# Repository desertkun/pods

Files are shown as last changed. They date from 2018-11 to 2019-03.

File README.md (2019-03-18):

# pods



Compact game console on `STM32F103RC6` chip with network module `NRF24L01` and `SH1106` display designed to be made as a pair.

To compile this, you'll need to install the [System Workbench for STM32](http://www.openstm32.org/Downloading%2Bthe%2BSystem%2BWorkbench%2Bfor%2BSTM32%2Binstaller) (requires an account to download).

The `layout` folder contains KiCad project for [schematics](https://user-images.githubusercontent.com/1666014/50406018-09bfe200-07c6-11e9-8298-aad8884d8a90.png).

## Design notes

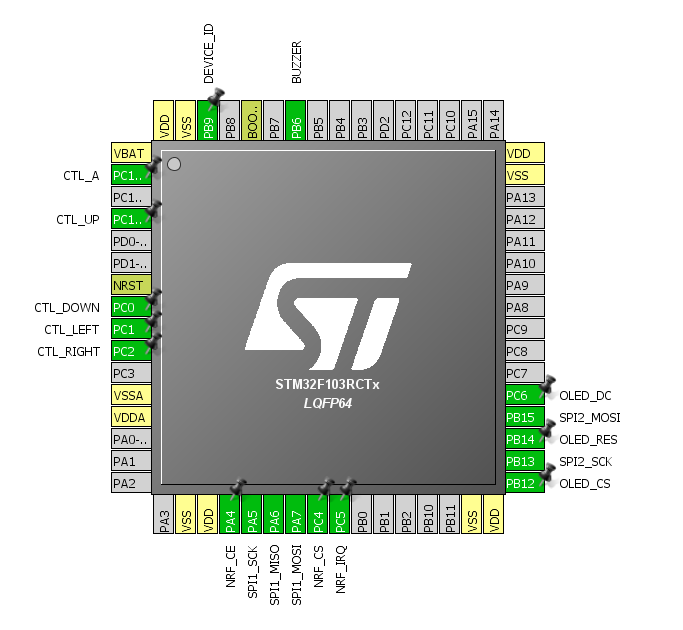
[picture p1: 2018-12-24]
datasheets/pinout.png

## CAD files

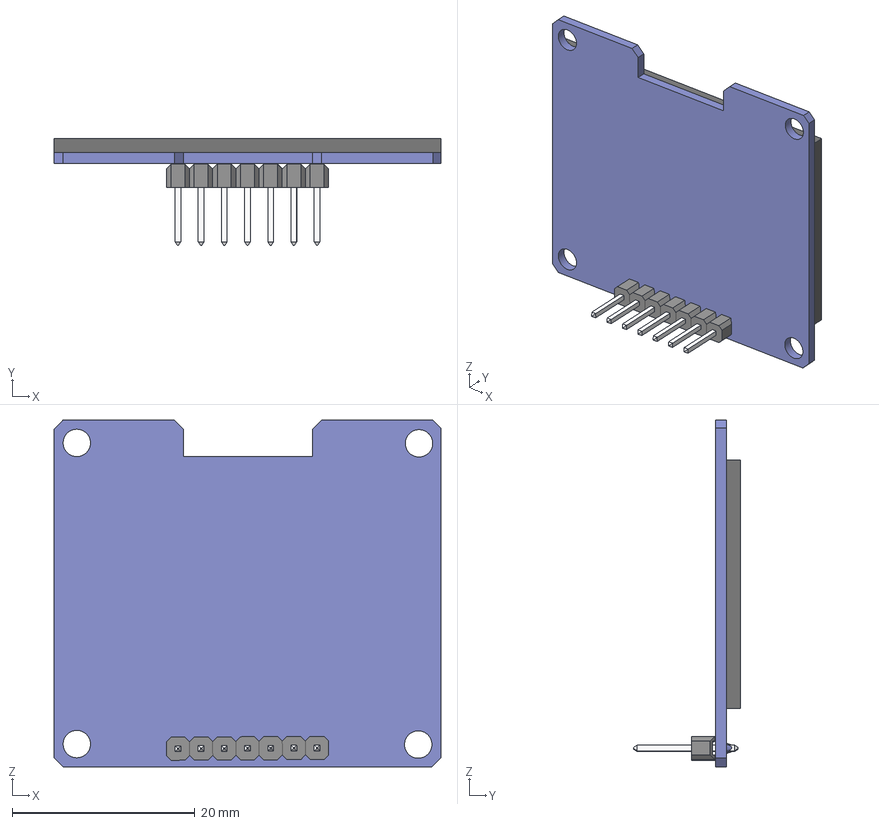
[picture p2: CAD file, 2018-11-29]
layout/3d/OLED Display 1.stp
42.4 x 11.7 x 38.0 mm

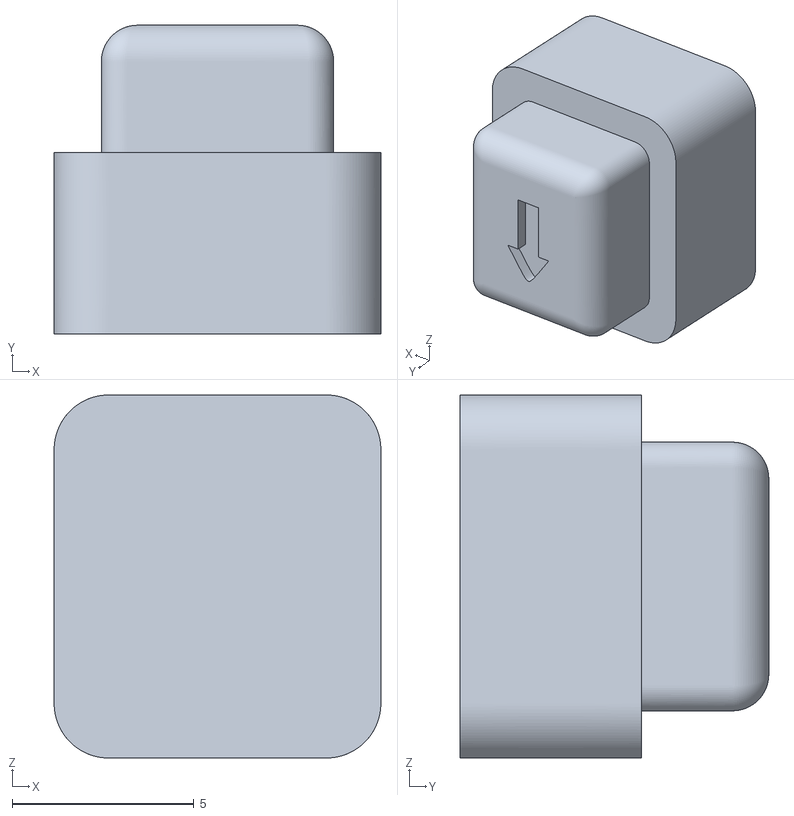
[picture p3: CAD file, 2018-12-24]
plot/3d/Arrow button.stl
9.00 x 8.50 x 10.0

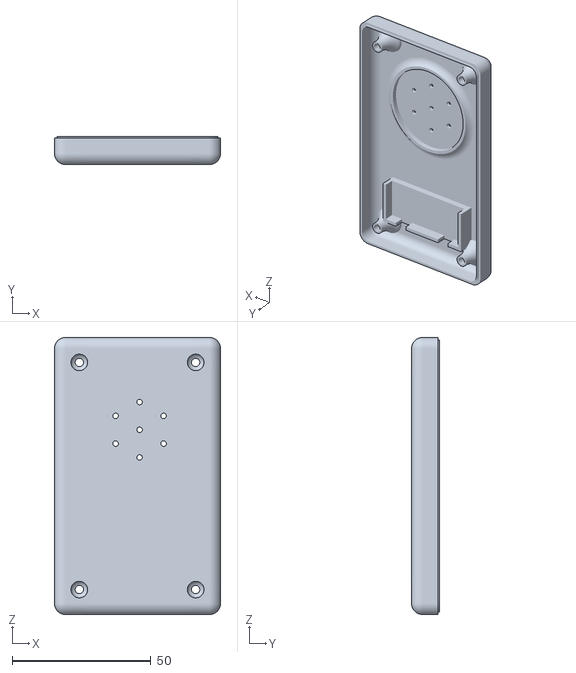
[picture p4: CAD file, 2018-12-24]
plot/3d/Bottom.stl
60.0 x 10.1 x 100.0

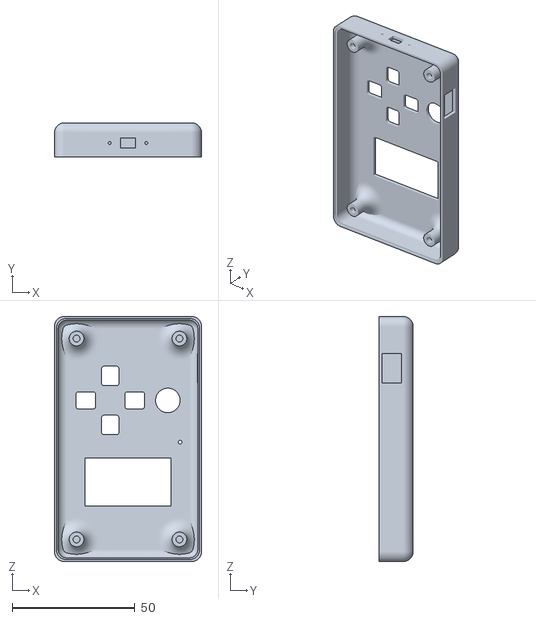
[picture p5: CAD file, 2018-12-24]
plot/3d/Top.stl
60.0 x 14.0 x 100.0

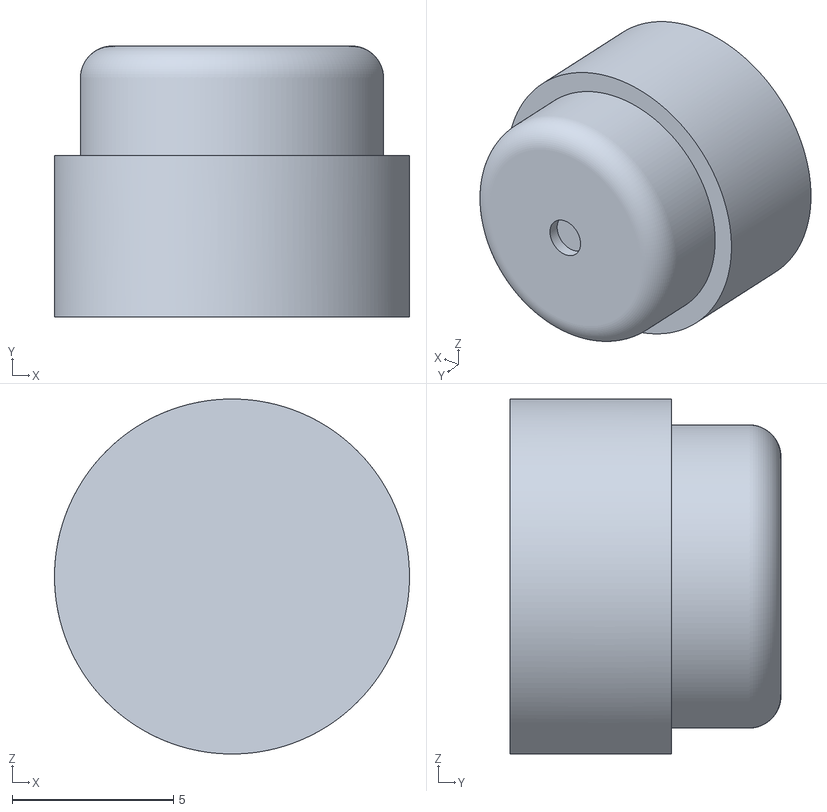
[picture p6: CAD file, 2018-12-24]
plot/3d/A button.stl
11.0 x 8.40 x 11.0

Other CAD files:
layout/3d/OLED Display 1.igs
layout/3d/OLED Display 1.stl

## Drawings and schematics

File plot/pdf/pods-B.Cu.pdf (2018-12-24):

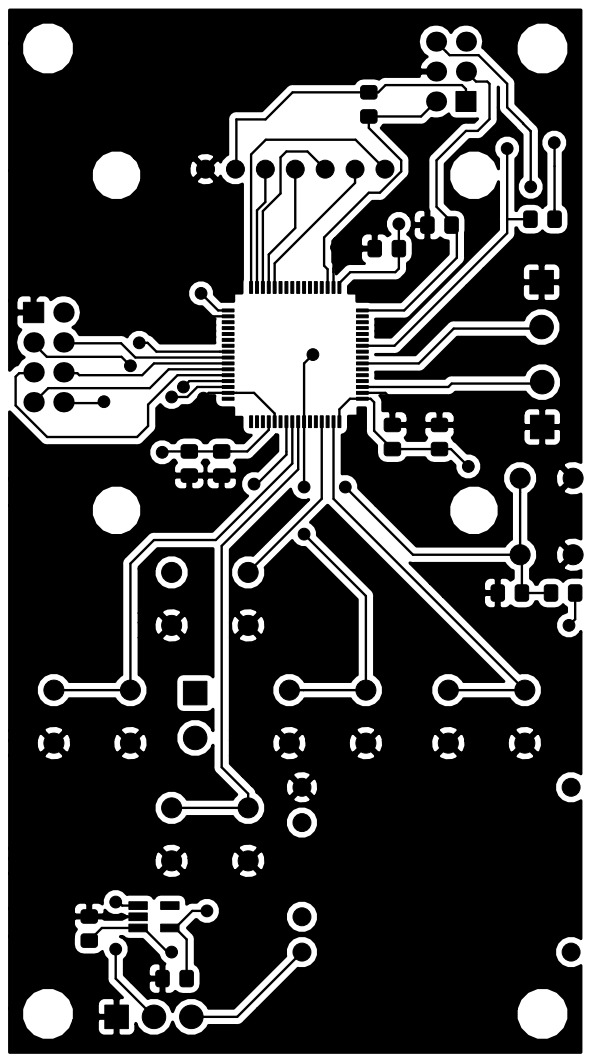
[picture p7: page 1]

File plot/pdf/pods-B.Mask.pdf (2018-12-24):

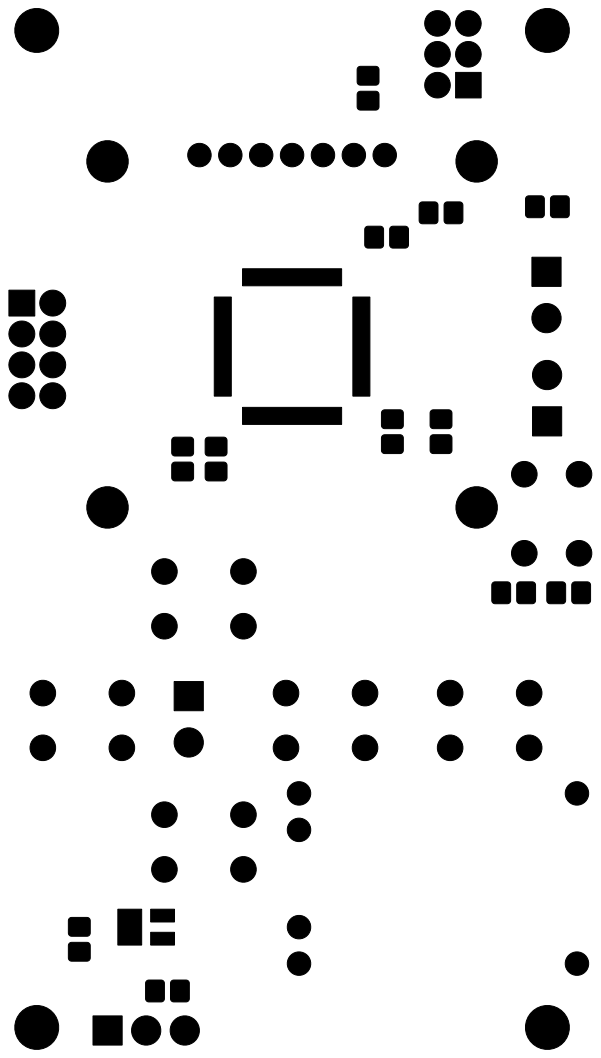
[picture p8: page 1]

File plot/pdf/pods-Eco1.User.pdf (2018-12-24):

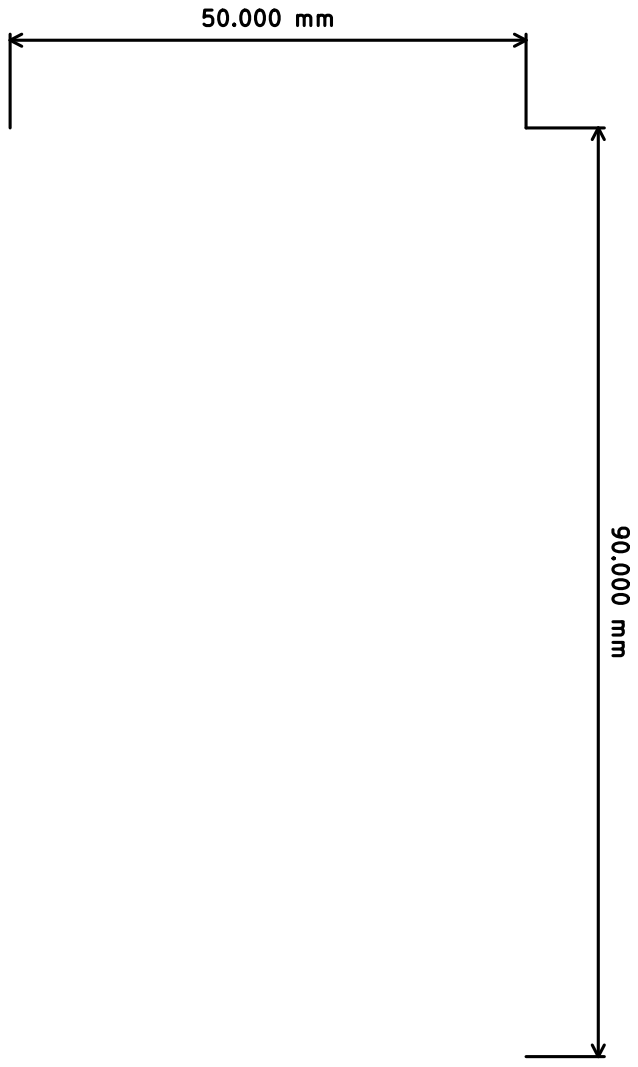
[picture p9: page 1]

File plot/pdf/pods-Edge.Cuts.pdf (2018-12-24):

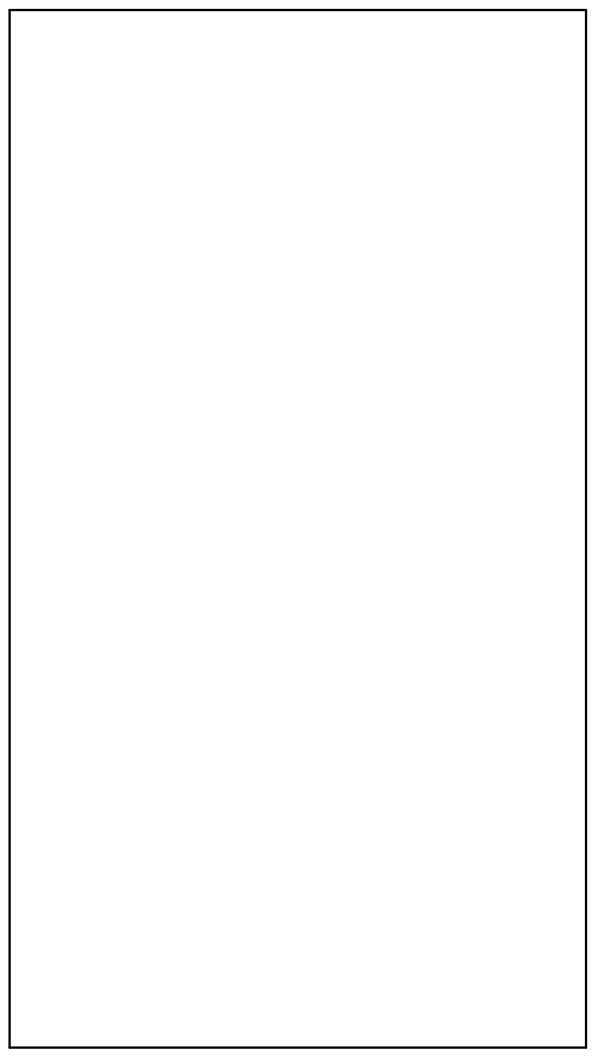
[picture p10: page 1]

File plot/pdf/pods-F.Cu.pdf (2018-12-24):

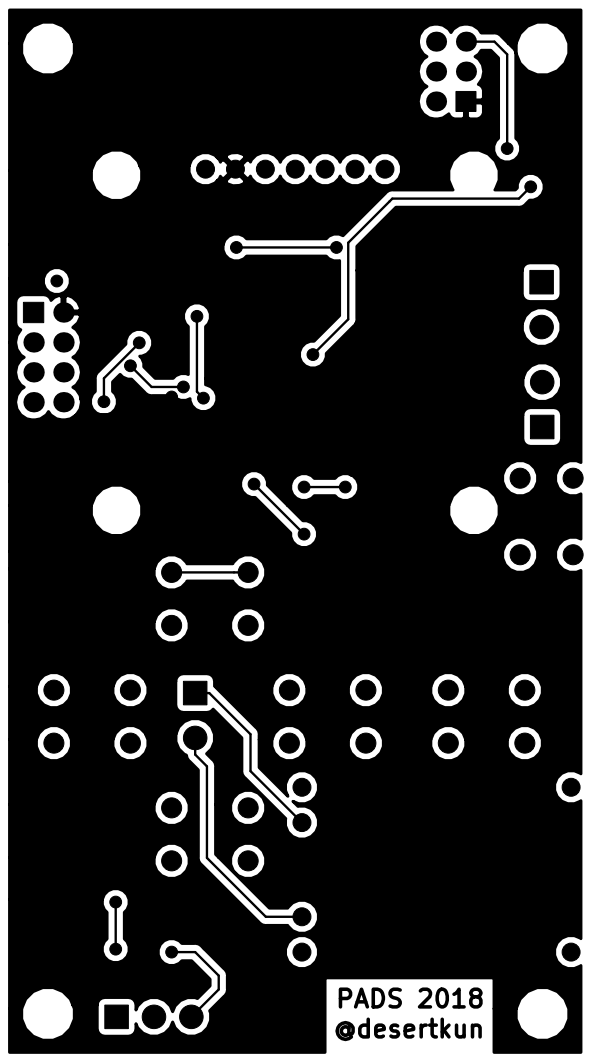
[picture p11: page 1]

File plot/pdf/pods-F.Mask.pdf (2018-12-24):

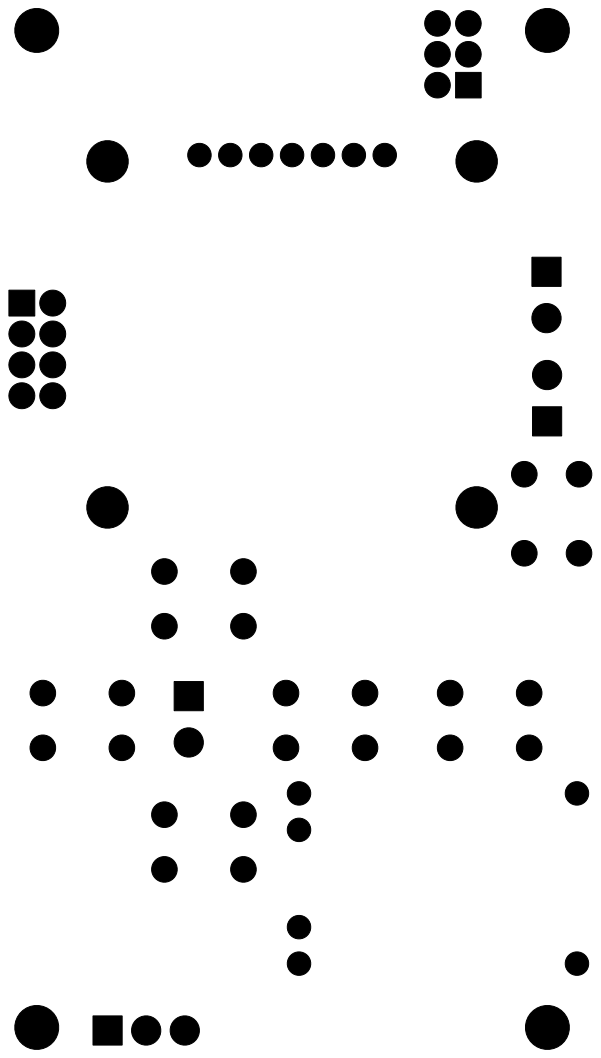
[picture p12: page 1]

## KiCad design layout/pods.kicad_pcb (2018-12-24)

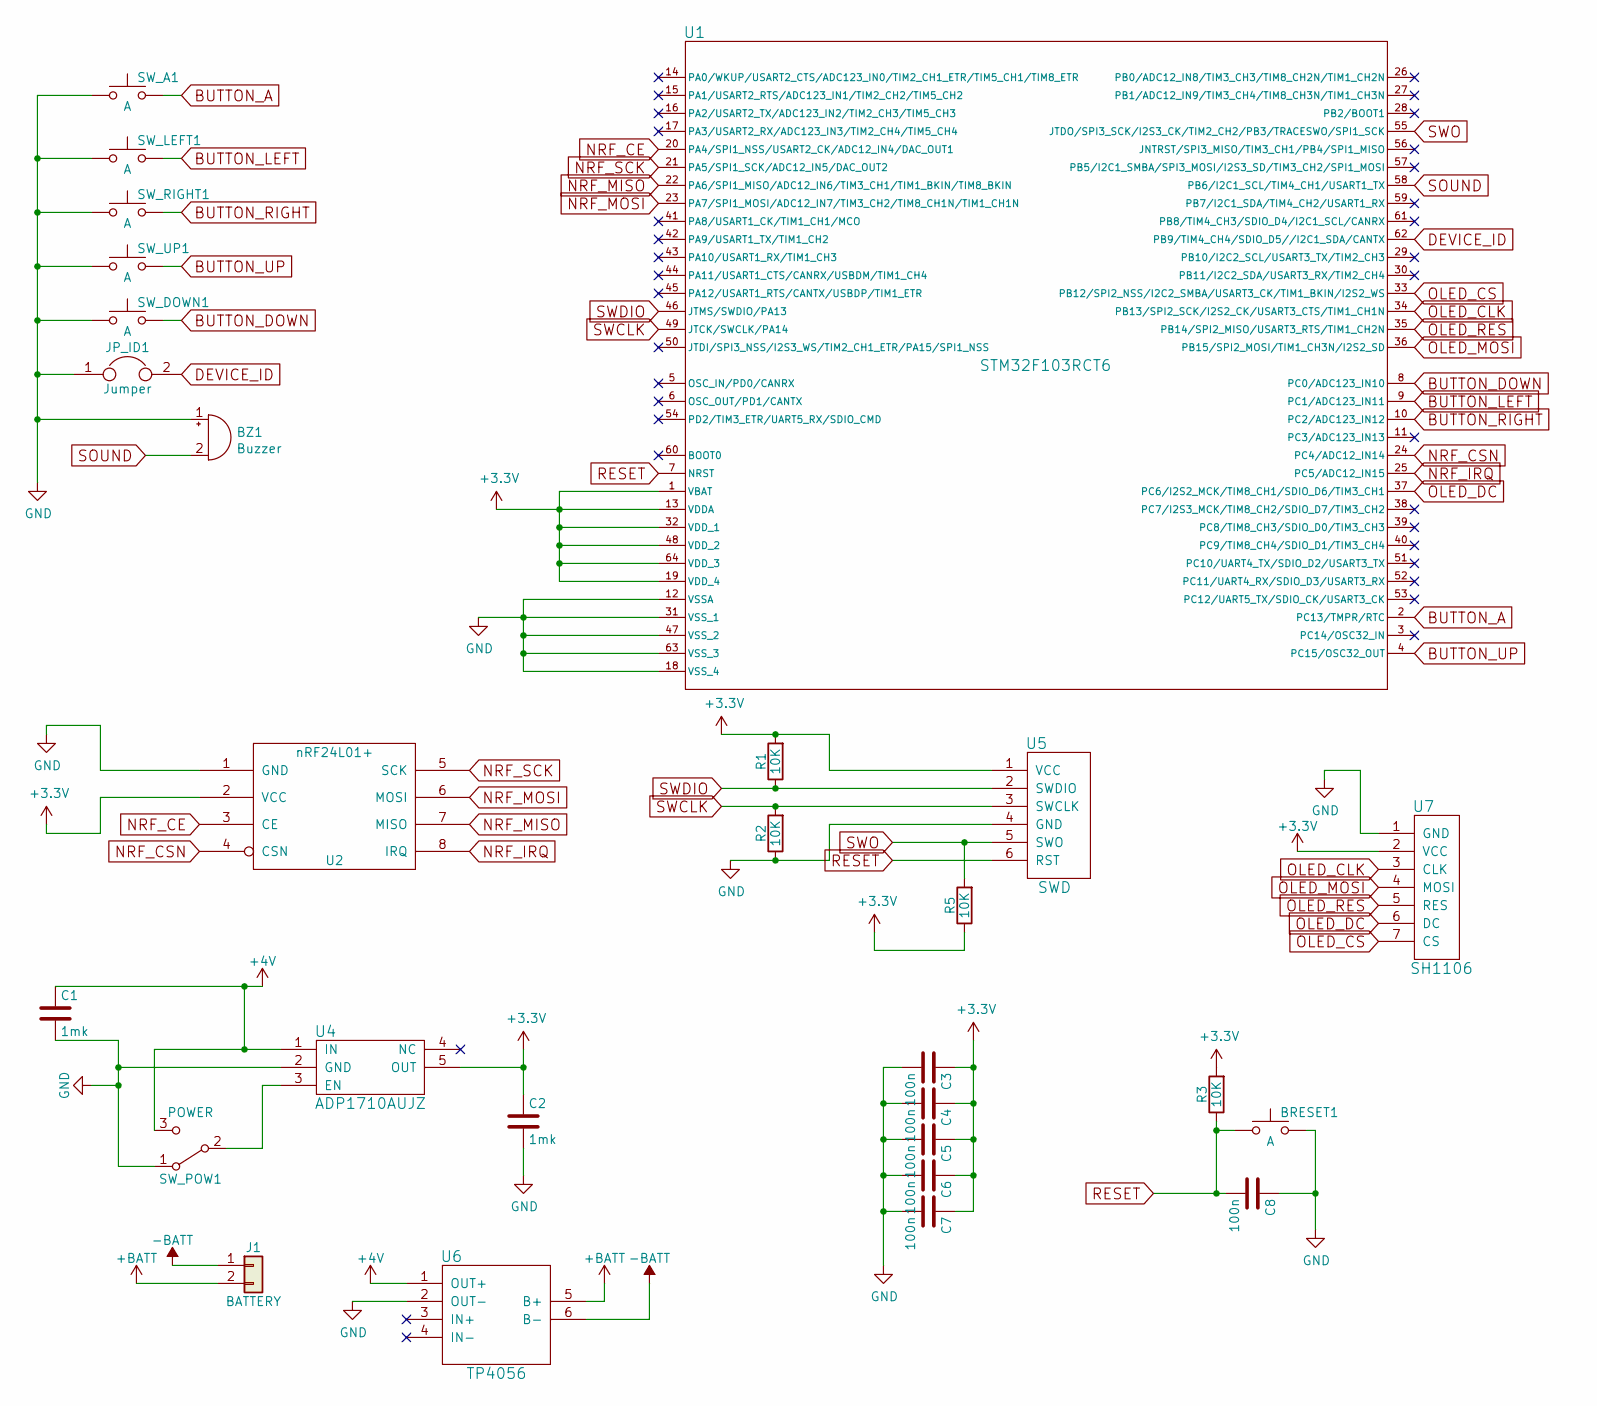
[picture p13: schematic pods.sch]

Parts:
BRESET1: A; SW_TH_Tactile_Omron_Fixed
BZ1: Buzzer; SolderWirePad_1x02_P3.81mm_Drill0.8mm
C1, C2: 1mk; C_0805_2012Metric_Pad1.15x1.40mm_HandSolder
C3, C4, C5, C6, C7, C8: 100n; C_0805_2012Metric_Pad1.15x1.40mm_HandSolder
J1: BATTERY; SolderWirePad_1x02_P3.81mm_Drill0.8mm
JP_ID1: Jumper; SolderWirePad_1x02_P3.81mm_Drill0.8mm
R1, R2, R3, R5: 10K; R_0805_2012Metric_Pad1.15x1.40mm_HandSolder
SW_A1: A; SW_TH_Tactile_Omron_Fixed
SW_DOWN1: A; SW_TH_Tactile_Omron_Fixed
SW_LEFT1: A; SW_TH_Tactile_Omron_Fixed
SW_POW1: POWER; SolderWirePad_1x03_P3.175mm_Drill0.8mm
SW_RIGHT1: A; SW_TH_Tactile_Omron_Fixed
SW_UP1: A; SW_TH_Tactile_Omron_Fixed
U1: STM32F103RCT6; LQFP-64_10x10mm_Pitch0.5mm
U2: nRF24L01+; NRF24L01
U4: ADP1710AUJZ; SOT-23-5_HandSoldering
U5: SWD; PinHeader_2x03_P2.54mm_Horizontal
U6: TP4056; tp4056
U7: SH1106; sh1106

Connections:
+3V3: C2.1, C3.1, C4.1, C5.1, C6.1, C7.1, R1.2, R3.2, R5.1, U1.1 (VBAT), U1.13 (VDDA), U1.19 (VDD_4), U1.32 (VDD_1), U1.48 (VDD_2), U1.64 (VDD_3), U2.2 (VCC), U4.5 (OUT), U5.1 (VCC), U7.2 (VCC)
+4V: C1.1, SW_POW1.3 (C), U4.1 (IN), U6.1 (OUT+)
+BATT: J1.2, U6.5 (B+)
-BATT: J1.1, U6.6 (B-)
BUTTON_A: SW_A1.2, U1.2 (PC13/TMPR/RTC)
BUTTON_DOWN: SW_DOWN1.2, U1.8 (PC0/ADC123_IN10)
BUTTON_LEFT: SW_LEFT1.2, U1.9 (PC1/ADC123_IN11)
BUTTON_RIGHT: SW_RIGHT1.2, U1.10 (PC2/ADC123_IN12)
BUTTON_UP: SW_UP1.2, U1.4 (PC15/OSC32_OUT)
DEVICE_ID: JP_ID1.2, U1.62 (PB9/TIM4_CH4/SDIO_D5//I2C1_SDA/CANTX)
GND: BRESET1.2, BZ1.1 (-), C1.2, C2.2, C3.2, C4.2, C5.2, C6.2, C7.2, C8.1, JP_ID1.1, R2.1, SW_A1.1, SW_DOWN1.1, SW_LEFT1.1, SW_POW1.1 (A), SW_RIGHT1.1, SW_UP1.1, U1.12 (VSSA), U1.18 (VSS_4), U1.31 (VSS_1), U1.47 (VSS_2), U1.63 (VSS_3), U2.1 (GND), U4.2 (GND), U5.4 (GND), U6.2 (OUT-), U7.1 (GND)
NRF_CE: U1.20 (PA4/SPI1_NSS/USART2_CK/ADC12_IN4/DAC_OU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), U2.3 (CE)
NRF_CSN: U1.24 (PC4/ADC12_IN14), U2.4 (CSN)
NRF_IRQ: U1.25 (PC5/ADC12_IN15), U2.8 (IRQ)
NRF_MISO: U1.22 (PA6/SPI1_MISO/ADC12_IN6/TIM3_CH1/TIM1_B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), U2.7 (MISO)
NRF_MOSI: U1.23 (PA7/SPI1_MOSI/ADC12_IN7/TIM3_CH2/TIM8_C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), U2.6 (MOSI)
NRF_SCK: U1.21 (PA5/SPI1_SCK/ADC12_IN5/DAC_OUT2), U2.5 (SCK)
unnamed: SW_POW1.2 (B), U4.3 (EN)
OLED_CLK: U1.34 (PB13/SPI2_SCK/I2S2_CK/USART3_CTS/TIM1_C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), U7.3 (CLK)
OLED_CS: U1.33 (PB12/SPI2_NSS/I2C2_SMBA/USART3_CK/TIM1_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), U7.7 (CS)
OLED_DC: U1.37 (PC6/I2S2_MCK/TIM8_CH1/SDIO_D6/TIM3_CH1), U7.6 (DC)
OLED_MOSI: U1.36 (PB15/SPI2_MOSI/TIM1_CH3N/I2S2_SD), U7.4 (MOSI)
OLED_RES: U1.35 (PB14/SPI2_MISO/USART3_RTS/TIM1_CH2N), U7.5 (RES)
RESET: BRESET1.1, C8.2, R3.1, U1.7 (NRST), U5.6 (RST)
SOUND: BZ1.2 (+), U1.58 (PB6/I2C1_SCL/TIM4_CH1/USART1_TX)
SWCLK: R2.2, U1.49 (JTCK/SWCLK/PA14), U5.3 (SWCLK)
SWDIO: R1.1, U1.46 (JTMS/SWDIO/PA13), U5.2 (SWDIO)
SWO: R5.2, U1.55 (JTDO/SPI3_SCK/I2S3_CK/TIM2_CH2/PB3/TRAC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), U5.5 (SWO)

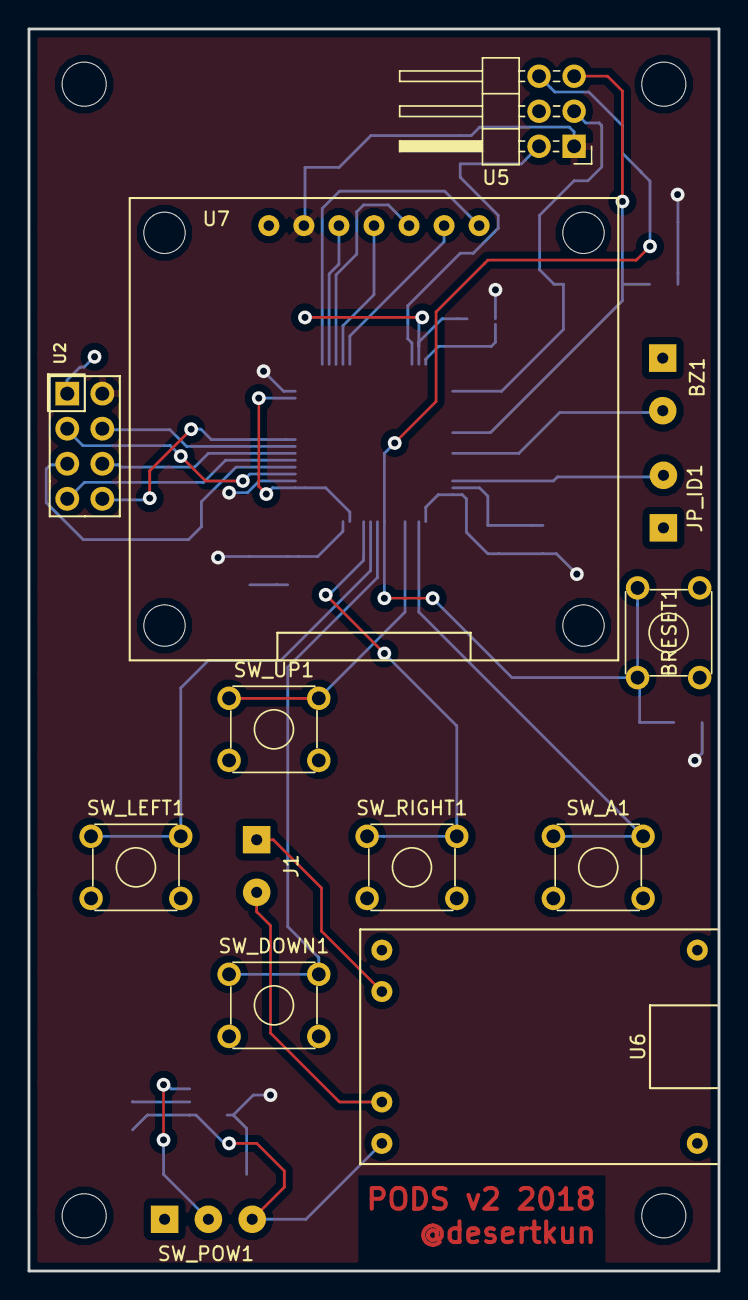
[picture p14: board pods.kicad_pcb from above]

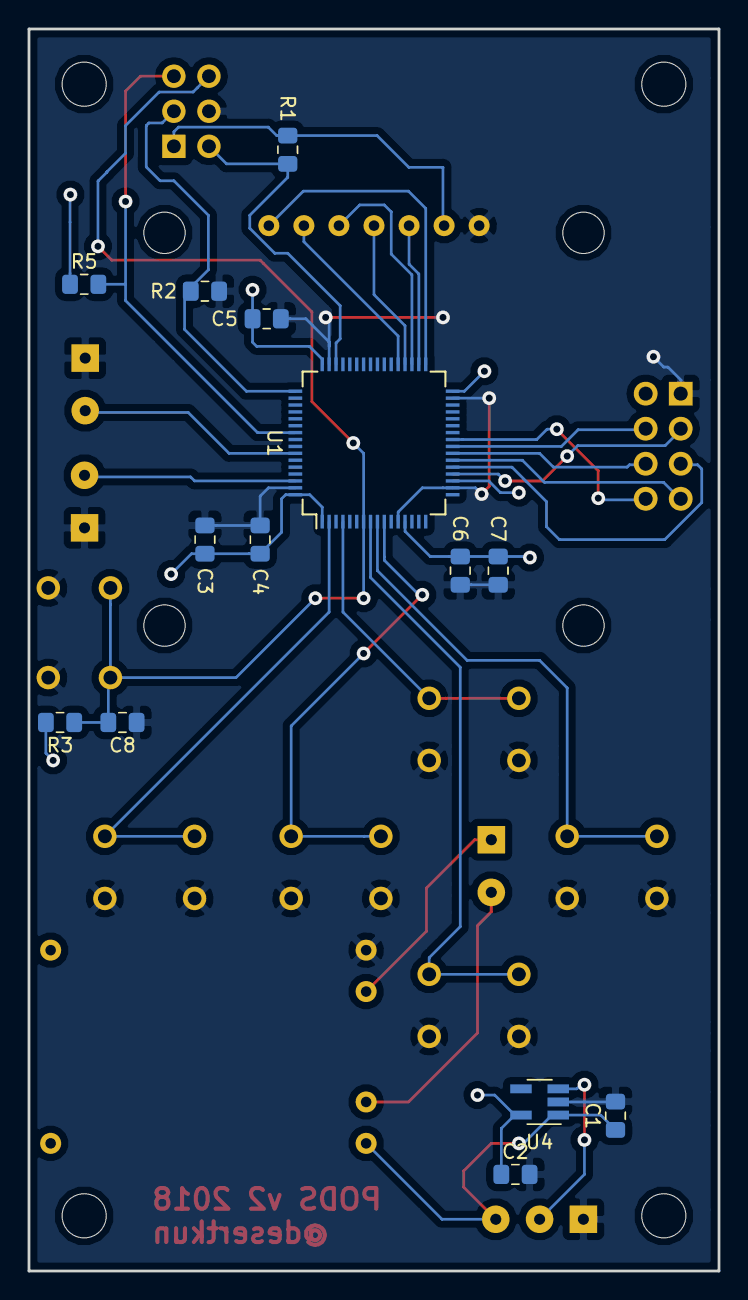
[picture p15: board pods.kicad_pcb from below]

Board: 2 copper layers, 50.0 x 90.0 mm, 28 parts (14 on the bottom side), 28 nets.

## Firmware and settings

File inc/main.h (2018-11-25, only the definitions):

#define CTL_A_Pin GPIO_PIN_13
#define CTL_A_GPIO_Port GPIOC
#define CTL_UP_Pin GPIO_PIN_15
#define CTL_UP_GPIO_Port GPIOC
#define CTL_DOWN_Pin GPIO_PIN_0
#define CTL_DOWN_GPIO_Port GPIOC
#define CTL_LEFT_Pin GPIO_PIN_1
#define CTL_LEFT_GPIO_Port GPIOC
#define CTL_RIGHT_Pin GPIO_PIN_2
#define CTL_RIGHT_GPIO_Port GPIOC
#define NRF_CE_Pin GPIO_PIN_4
#define NRF_CE_GPIO_Port GPIOA
#define NRF_CS_Pin GPIO_PIN_4
#define NRF_CS_GPIO_Port GPIOC
#define NRF_IRQ_Pin GPIO_PIN_5
#define NRF_IRQ_GPIO_Port GPIOC
#define NRF_IRQ_EXTI_IRQn EXTI9_5_IRQn
#define OLED_CS_Pin GPIO_PIN_12
#define OLED_CS_GPIO_Port GPIOB
#define OLED_RES_Pin GPIO_PIN_14
#define OLED_RES_GPIO_Port GPIOB
#define OLED_DC_Pin GPIO_PIN_6
#define OLED_DC_GPIO_Port GPIOC
#define BUZZER_Pin GPIO_PIN_6
#define BUZZER_GPIO_Port GPIOB
#define DEVICE_ID_Pin GPIO_PIN_9
#define DEVICE_ID_GPIO_Port GPIOB

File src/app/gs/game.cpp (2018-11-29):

/*
 * game.cpp
 *
 *  Created on: Mar 11, 2018
 *      Author: desertkun
 */


#include "app/gs/game.h"
#include "app/gs/mainmenu.h"
#include "app/gs/result.h"
#include "app/application.h"
#include "device/display.h"
#include "device/network.h"
#include "device/system.h"
#include "device/sound.h"
#include "app/melodies.h"
#include "app/messages.h"

#include <cstring>
#include <stdlib.h>

extern const unsigned char tile_wall_bmp [];
extern const unsigned char tile_block_bmp [];
extern const unsigned char tile_bomb_1_bmp [];
extern const unsigned char tile_bomb_2_bmp [];
extern const unsigned char tile_bomb_3_bmp [];
extern const unsigned char tile_bomb_4_bmp [];
extern const unsigned char tile_character_a_bmp [];
extern const unsigned char tile_character_b_bmp [];
extern const unsigned char tile_explosion_1_bmp [];
extern const unsigned char tile_explosion_2_bmp [];
extern const unsigned char tile_star_1_bmp [];
extern const unsigned char tile_star_2_bmp [];
extern const unsigned char tile_empty_bmp [];
extern const unsigned char tile_bomb_bonus_1_bmp [];
extern const unsigned char tile_bomb_bonus_2_bmp [];


namespace gs
{

Game Game::s_instance = Game();

int8_t sgn(int8_t val) {
    return (int8_t(0) < val) - (val < int8_t(0));
}

const uint32_t Bomb::TIME = 4000;
const uint32_t Bomb::EXPLOSION_TIME = 600;


void Bomb::place(uint8_t x, uint8_t y, uint8_t power)
{
	this->x = x;
	this->y = y;
	this->power = power;

	timer = 0;
	state = BombState::active;
	_render = true;

	device::Sound::playMelody(&Melodies::PlaceBomb[0]);

	Game::SetDirty();
}

void Bomb::removeExplosions()
{
	state = BombState::normal;
	timer = 0;

	Game& game = Game::s_instance;
	game.removeShake();

	game.setTile(x, y, Tile::empty);

	// left
	for (uint8_t _x = x - 1, p = power; _x >= 0 && p > 0; _x--, p--)
	{
		if (game.getTile(_x, y) != Tile::explosion)
			break;

		game.setTile(_x, y, Tile::empty);
	}

	// right
	for (uint8_t _x = x + 1, p = power; _x <= MAP_WIDTH - 1 && p > 0; _x++, p--)
	{
		if (game.getTile(_x, y) != Tile::explosion)
			break;

		game.setTile(_x, y, Tile::empty);
	}

	// up
	for (uint8_t _y = y - 1, p = power; _y >= 0 && p > 0; _y--, p--)
	{
		if (game.getTile(x, _y) != Tile::explosion)
			break;

		game.setTile(x, _y, Tile::empty);
	}

	// down
	for (uint8_t _y = y + 1, p = power; _y <= MAP_HEIGHT - 1 && p > 0; _y++, p--)
	{
		if (game.getTile(x, _y) != Tile::explosion)
			break;

		game.setTile(x, _y, Tile::empty);
	}

	Game::SetDirty();
}

void Bomb::explode()
{
	Game& game = Game::s_instance;

	device::Sound::playMelody(&Melodies::Bomb[0]);

	game.addShake();
	game.setTile(x, y, Tile::explosion);

	// left
	for (uint8_t _x = x - 1, p = power; _x >= 0 && p > 0; _x--, p--)
	{
		if (game.checkTile(_x, y))
			break;

		game.setTile(_x, y, Tile::explosion);
	}

	// right
	for (uint8_t _x = x + 1, p = power; _x <= MAP_WIDTH - 1 && p > 0; _x++, p--)
	{
		if (game.checkTile(_x, y))
			break;

		game.setTile(_x, y, Tile::explosion);
	}

	// up
	for (uint8_t _y = y - 1, p = power; _y >= 0 && p > 0; _y--, p--)
	{
		if (game.checkTile(x, _y))
			break;

		game.setTile(x, _y, Tile::explosion);
	}

	// down
	for (uint8_t _y = y + 1, p = power; _y <= MAP_HEIGHT - 1 && p > 0; _y++, p--)
	{
		if (game.checkTile(x, _y))
			break;

		game.setTile(x, _y, Tile::explosion);
	}

	state = BombState::explosion;
	timer = 0;

	Game::SetDirty();
}

void Bomb::update(uint32_t dt)
{
	switch (state)
	{
		case BombState::active:
		{
			timer += dt;

			bool now = timer % 500 > 250;

			if (now != _render)
			{
				_render = now;
				Game::SetDirty();
			}

			if (timer > Bomb::TIME)
			{
				explode();
			}

			break;
		}
		case BombState::explosion:
		{
			timer += dt;

			if (timer > Bomb::EXPLOSION_TIME)
			{
				removeExplosions();
			}

			Game::SetDirty();

			break;
		}
		default:
		{
			break;
		}
	}

}

void Bomb::render()
{
	if (state != BombState::active)
		return;

	const uint8_t* sprite;

	if (timer < 1000)
	{
		sprite = tile_bomb_1_bmp;
	}
	else if (timer < 2000)
	{
		sprite = tile_bomb_2_bmp;
	}
	else if (timer < 3000)
	{
		sprite = tile_bomb_3_bmp;
	}
	else
	{
		sprite = tile_bomb_4_bmp;
	}

	if (!_render)
		return;

	device::Display::drawImage(
		MAP_OFFSET_X + x * 8,
		MAP_OFFSET_Y + y * 8,
		8, 8, sprite);
}

///////////

void Player::moved()
{
	Game& game = Game::s_instance;

	Tile at = game.getTile(x, y);

	if (at == Tile::powerup)
	{
		device::Sound::playMelody(&Melodies::Pickup[0]);

		device::Display::invertDisplay(true);
		HAL_Delay(50);
		device::Display::invertDisplay(false);

		game.removePowerUp();
		game.setTile(x, y, Tile::empty);

		if (bombPower < 5)
			bombPower++;
	}

	if (at == Tile::extraBomb)
	{
		device::Sound::playMelody(&Melodies::Pickup[0]);

		device::Display::invertDisplay(true);
		HAL_Delay(50);
		device::Display::invertDisplay(false);

		game.removePowerUp();
		game.setTile(x, y, Tile::empty);

		if (bombCount < MAX_BOMBS)
			bombCount++;
	}
}

void Player::update(uint32_t dt)
{
	for (uint8_t i = 0; i < MAX_BOMBS; i++)
	{
		bombs[i].update(dt);
	}

	switch (state)
	{
		case PlayerState::moving:
		{
			movingTimer += dt;

			if (movingTimer >= 16)
			{
				movingTimer = 0;

				int8_t signX = sgn((int8_t)targetX - (int8_t)x),
					   signY = sgn((int8_t)targetY - (int8_t)y);

				offsetX += signX;
				offsetY += signY;
				movedBy += 1;

				Game::SetDirty();

				if (movedBy >= 8)
				{
					x = targetX;
					y = targetY;
					offsetX = 0;
					offsetY = 0;
					movedBy = 0;
					movingTimer = 0;
					state = PlayerState::normal;

					moved();
				}
			}


			break;
		}
		default:
		{
			break;
		}
	}
}

void Player::moveTo(uint8_t x, uint8_t y)
{
	targetX = x;
	targetY = y;
	offsetX = 0;
	offsetY = 0;
	movedBy = 0;
	movingTimer = 0;

	state = PlayerState::moving;
}

void Player::init(uint8_t x, uint8_t y, const unsigned char* sprite)
{
	this->x = x;
	this->y = y;
	this->sprite = sprite;

	for (uint8_t i = 0; i < MAX_BOMBS; i++)
	{
		Bomb& bomb = bombs[i];
		bomb.state = BombState::normal;
		bomb.timer = 0;
		bomb._render = false;
		bomb.power = 1;
	}

	bombPower = 1;
	bombCount = 1;
	offsetX = 0;
	offsetY = 0;
	movingTimer = 0;
	state = PlayerState::normal;
}

void Player::render()
{
	device::Display::drawImage(
		MAP_OFFSET_X + x * 8 + offsetX,
		MAP_OFFSET_Y + y * 8 + offsetY,
		8, 8, sprite);


	for (uint8_t i = 0; i < MAX_BOMBS; i++)
	{
		bombs[i].render();
	}
}

/////////
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

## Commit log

2018-03-10 Network working prototype
    [layout.fzz, stm_link_1.cfg, stm_link_2.cfg]
2018-11-21 Some progress
    [layout.fzz, pods-2018-11-21-16-58-43.sch, pods.kicad_pcb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]
2018-11-24 Working prototype
    Fixed network
    Full-blown music
    Moving characters
    [application.cpp, game.cpp, game.h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]
2018-11-29 New PCB design
    [OLED Display 1.igs, OLED Display 1.stl, OLED Display 1.stp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]
2018-12-02 Updated kicad design
    [pods.kicad_pcb, pods.sch]
2018-12-24 Updated schematic/pcb
    [A button.stl, Arrow button.stl, Bottom.stl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]

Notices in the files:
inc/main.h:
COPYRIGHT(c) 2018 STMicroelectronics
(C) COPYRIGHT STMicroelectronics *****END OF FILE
